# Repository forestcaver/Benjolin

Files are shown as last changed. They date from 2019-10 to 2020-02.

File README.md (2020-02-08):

# Benjolin

CC-By-NC 4.0, 2019

SMT Benjolin. Strictly for non-commercial use.

- - - -

This is a SMT version of the Benjolin with some modifications to power supply and protection.

Built and verified, Oct 2019

Rob Hordijk (the designer of the Benjolin) has kindly given permission Oct 27, 2019) for this to be shared on GitHub with the proviso that these files cannot be used by third parties for commercial use.

If you make changes and want to republish, please contact Rob before doing so!

- - - -

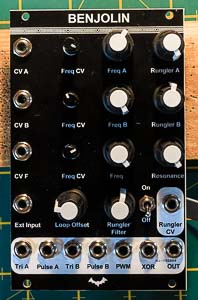
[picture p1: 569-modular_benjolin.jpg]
Benjolin


- - - -

## v1.0 ##

Files: Eagle pcb board, Eagle pcb schematic, Gerber files for the pcb, Eagle panel board, Gerber files for the panel (I use one-sided aluminium pcb with no copper), 2x images of the finished module

I used a combination of Kweiwen's schematic on his github as well as the electro-music schematics. I then added the power supply and protection.

The main issue (which is an original feature) for me is that the output volume is quite low. This is true of the original design. You can adjust one of the resistors just before the filter to boost the gain. But this can cause subtle distortion in the filter. A better way is to add a gain cell at the output (see v1.6)

- - - -

## v1.6 ##

This version adds an opamp to add gain to the output to approx 10v p-p. It also normalises T1 to osc 2 cv input
(can still be attenuated with the pot), normalises T2 to osc 1 cv and T2 to filter cv input.

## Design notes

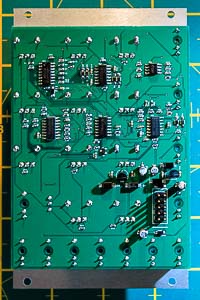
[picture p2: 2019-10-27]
568-modular_benjolin.jpg

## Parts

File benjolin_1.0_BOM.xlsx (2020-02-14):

benjolin_1.0_BOM
Qty | Value | Device | Package | Parts | Description | PROD_ID | VALUE
1 | 1.5k | R-US_R0603 | R0603 | R40 | RESISTOR, American symbol
6 | 100k | R-US_R0603 | R0603 | R11, R12, R17, R31, R44, R45 | RESISTOR, American symbol
17 | 100n | C-EUC0603 | C0603 | C5, C11, C12, C13, C14, C17, C18, C19, C20, C21, C22, C23, C24, C25, C26, C27, C28 | CAPACITOR, European symbol
3 | 10k | POT_USVERTICAL_NARROW | ALPS_POT_NARROW | R51, R52, R53
8 | 10k | POT_USVERTICAL_PS | ALPS_POT_VERTICAL_PS | R54, R55, R56, R57, R58, R59, R60, R61
5 | 10k | R-US_R0603 | R0603 | R7, R8, R29, R38, R46 | RESISTOR, American symbol
2 | 10u | CPOL-USA | PANASONIC_A | C15, C16 | POLARIZED CAPACITOR, American symbol
1 | 150k | R-US_R0603 | R0603 | R36 | RESISTOR, American symbol
5 | 15k | R-US_R0603 | R0603 | R13, R14, R22, R26, R39 | RESISTOR, American symbol
6 | 1N4148W-7 | 1N4148W-7 | SOD123 | D1, D2, D3, D4, D5, D6 | DIODE
3 | 1N5819HW | DIODE-SOD123 | SOD123 | D11, D100, D200 | DIODE
2 | 1n | C-EUC0603 | C0603 | C3, C4 | CAPACITOR, European symbol
4 | 1n4004 | D-SMA | DO-214AC | D7, D8, D9, D10 | DIODE
3 | 220p | C-EUC0603 | C0603 | C7, C8, C10 | CAPACITOR, European symbol
1 | 2n3904 | TRANS_NPN-MMBT2222AL | SOT23-3 | Q1 | NPN transistor | TRANS-08049 | 600mA/40V
16 | 30k | R-US_R0603 | R0603 | R3, R5, R15, R16, R19, R20, R23, R24, R25, R27, R28, R32, R33, R34, R47, R48 | RESISTOR, American symbol
2 | 4.7u | CPOL-USA | PANASONIC_A | C100, C200 | POLARIZED CAPACITOR, American symbol
1 | 4021D | 4021D | SO16 | IC1 | 8-bit static SHIFT REGISTER
1 | 470k | R-US_R0603 | R0603 | R50 | RESISTOR, American symbol
1 | 47k (was 62k) | R-US_R0603 | R0603 | R18 | RESISTOR, American symbol
4 | 510 | R-US_R0603 | R0603 | R9, R10, R37, R49 | RESISTOR, American symbol
9 | 51k | R-US_R0603 | R0603 | R1, R2, R4, R6, R30, R35, R41, R42, R43 | RESISTOR, American symbol
4 | 560p | C-EUC0603 | C0603 | C1, C2, C6, C9 | CAPACITOR, European symbol
1 | 62k | R-US_R0603 | R0603 | R21 | RESISTOR, American symbol
1 | M05X2PTH | M05X2PTH | AVR_ICSP | JP1 | Header 5x2
12 | PJ301_THONKICONN6 | PJ301_THONKICONN6 | WQP_PJ_301M6 | J1, J2, J3, J4, J5, J6, J7, J8, J9, J10, J11, J12
1 | SSM2164S | SSM2164S | SOIC16N | IC3
1 | TL072D | TL072D | SO08 | IC4 | OP AMP
3 | TL074D | TL074D | SO14 | IC2, IC5, IC6 | OP AMP
1 | lm78l09 | 78LXX | 78LXX | IC7 | VOLTAGE REGULATOR
1 | lm79l09 | 79LXX | 79LXX | IC8 | VOLTAGE REGULATOR
1 | submini-2T | SPDTT | SPDT-SUB | SW1 | SPDT Switch

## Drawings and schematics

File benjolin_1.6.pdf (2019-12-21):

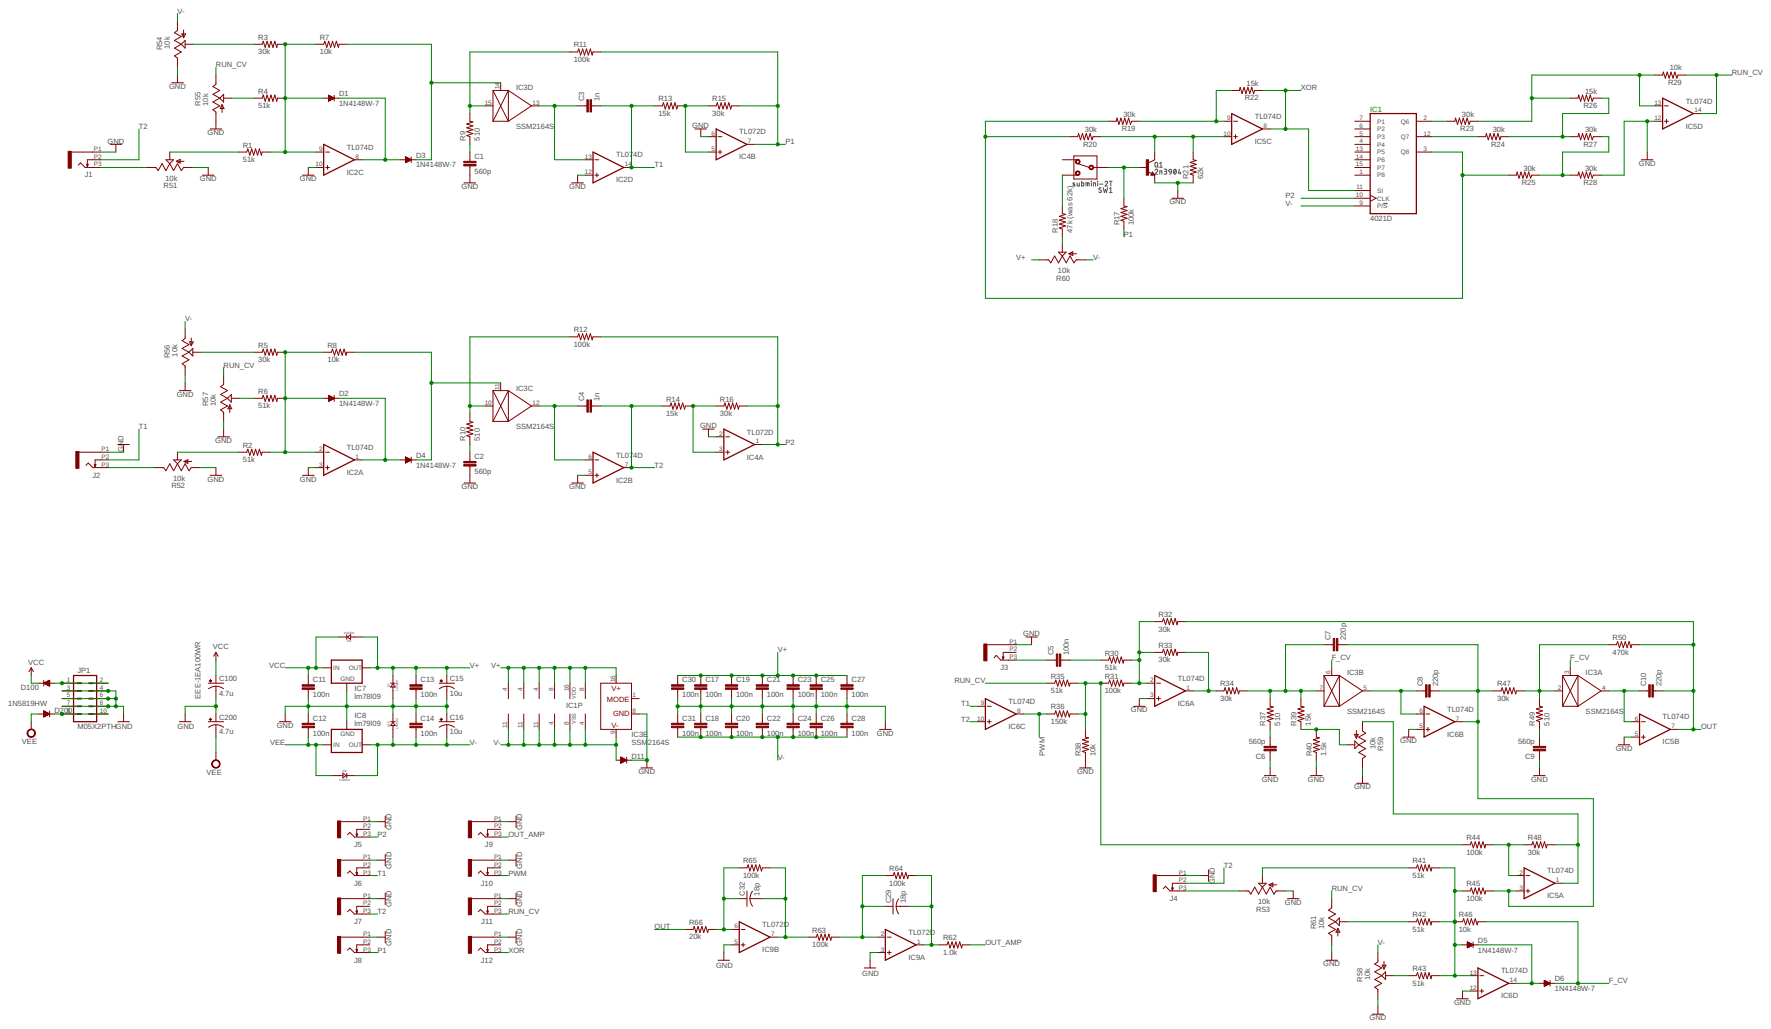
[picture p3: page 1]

GND GND

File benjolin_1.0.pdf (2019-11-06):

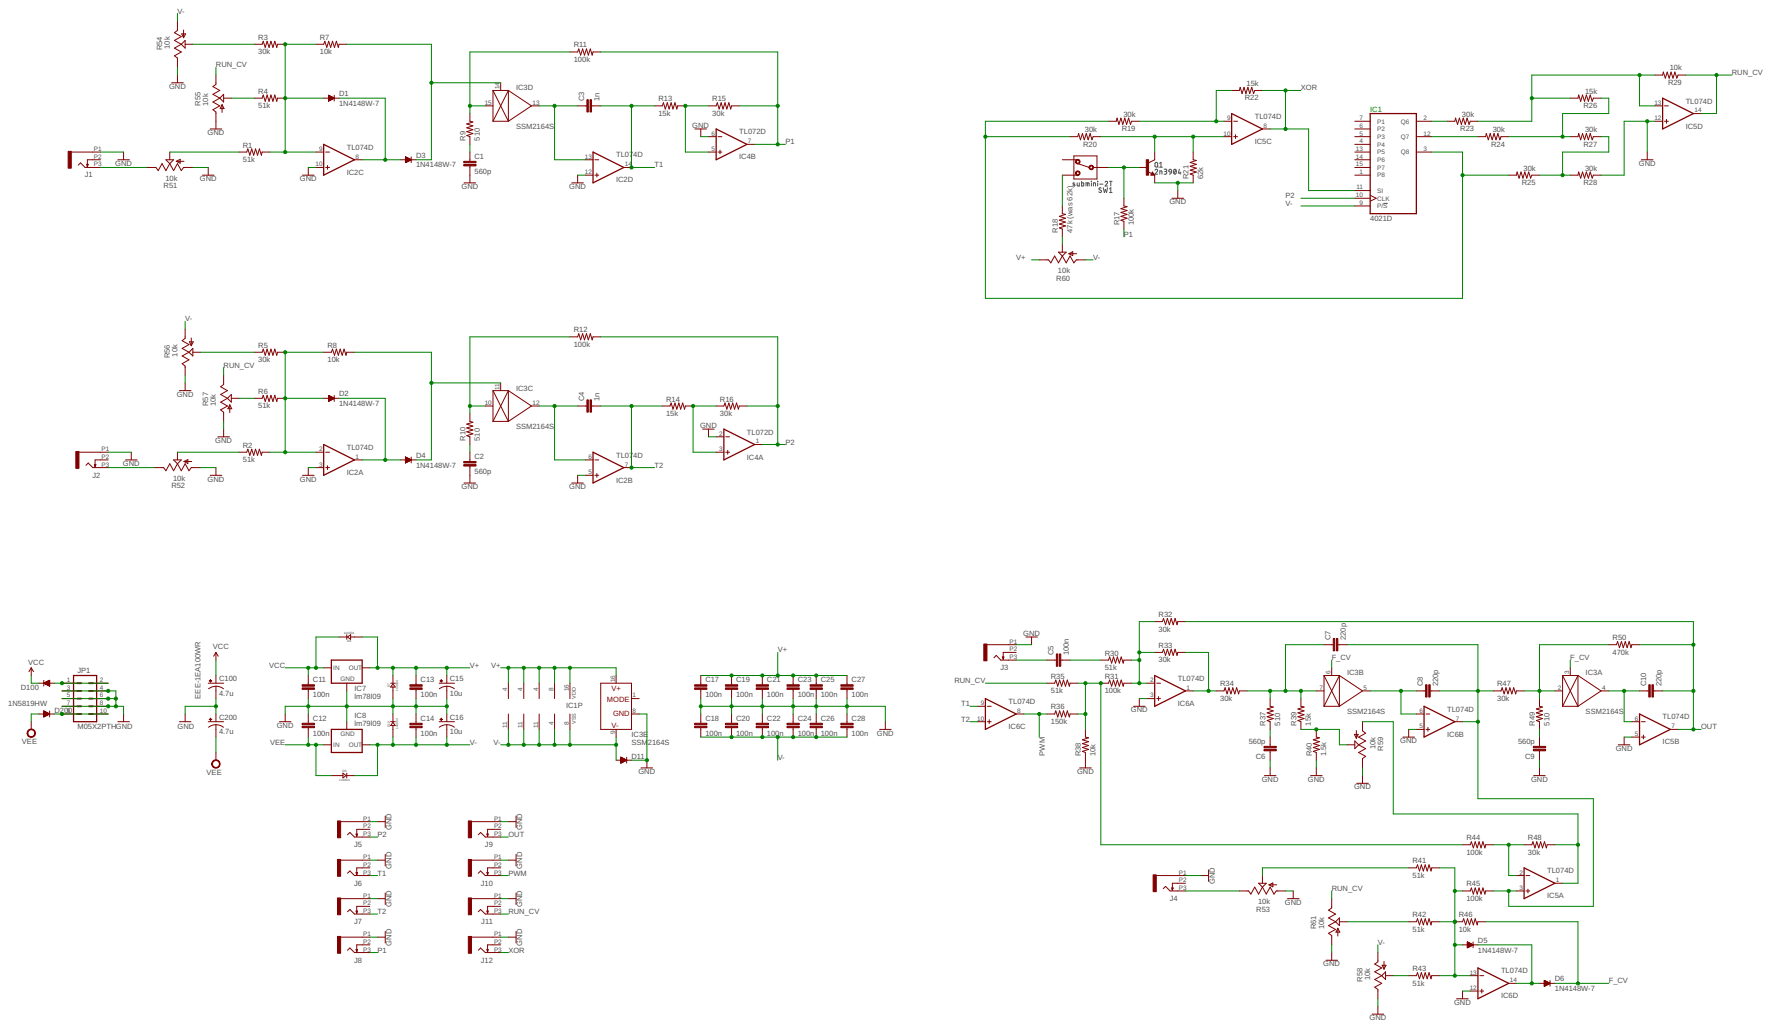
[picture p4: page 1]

GND GND

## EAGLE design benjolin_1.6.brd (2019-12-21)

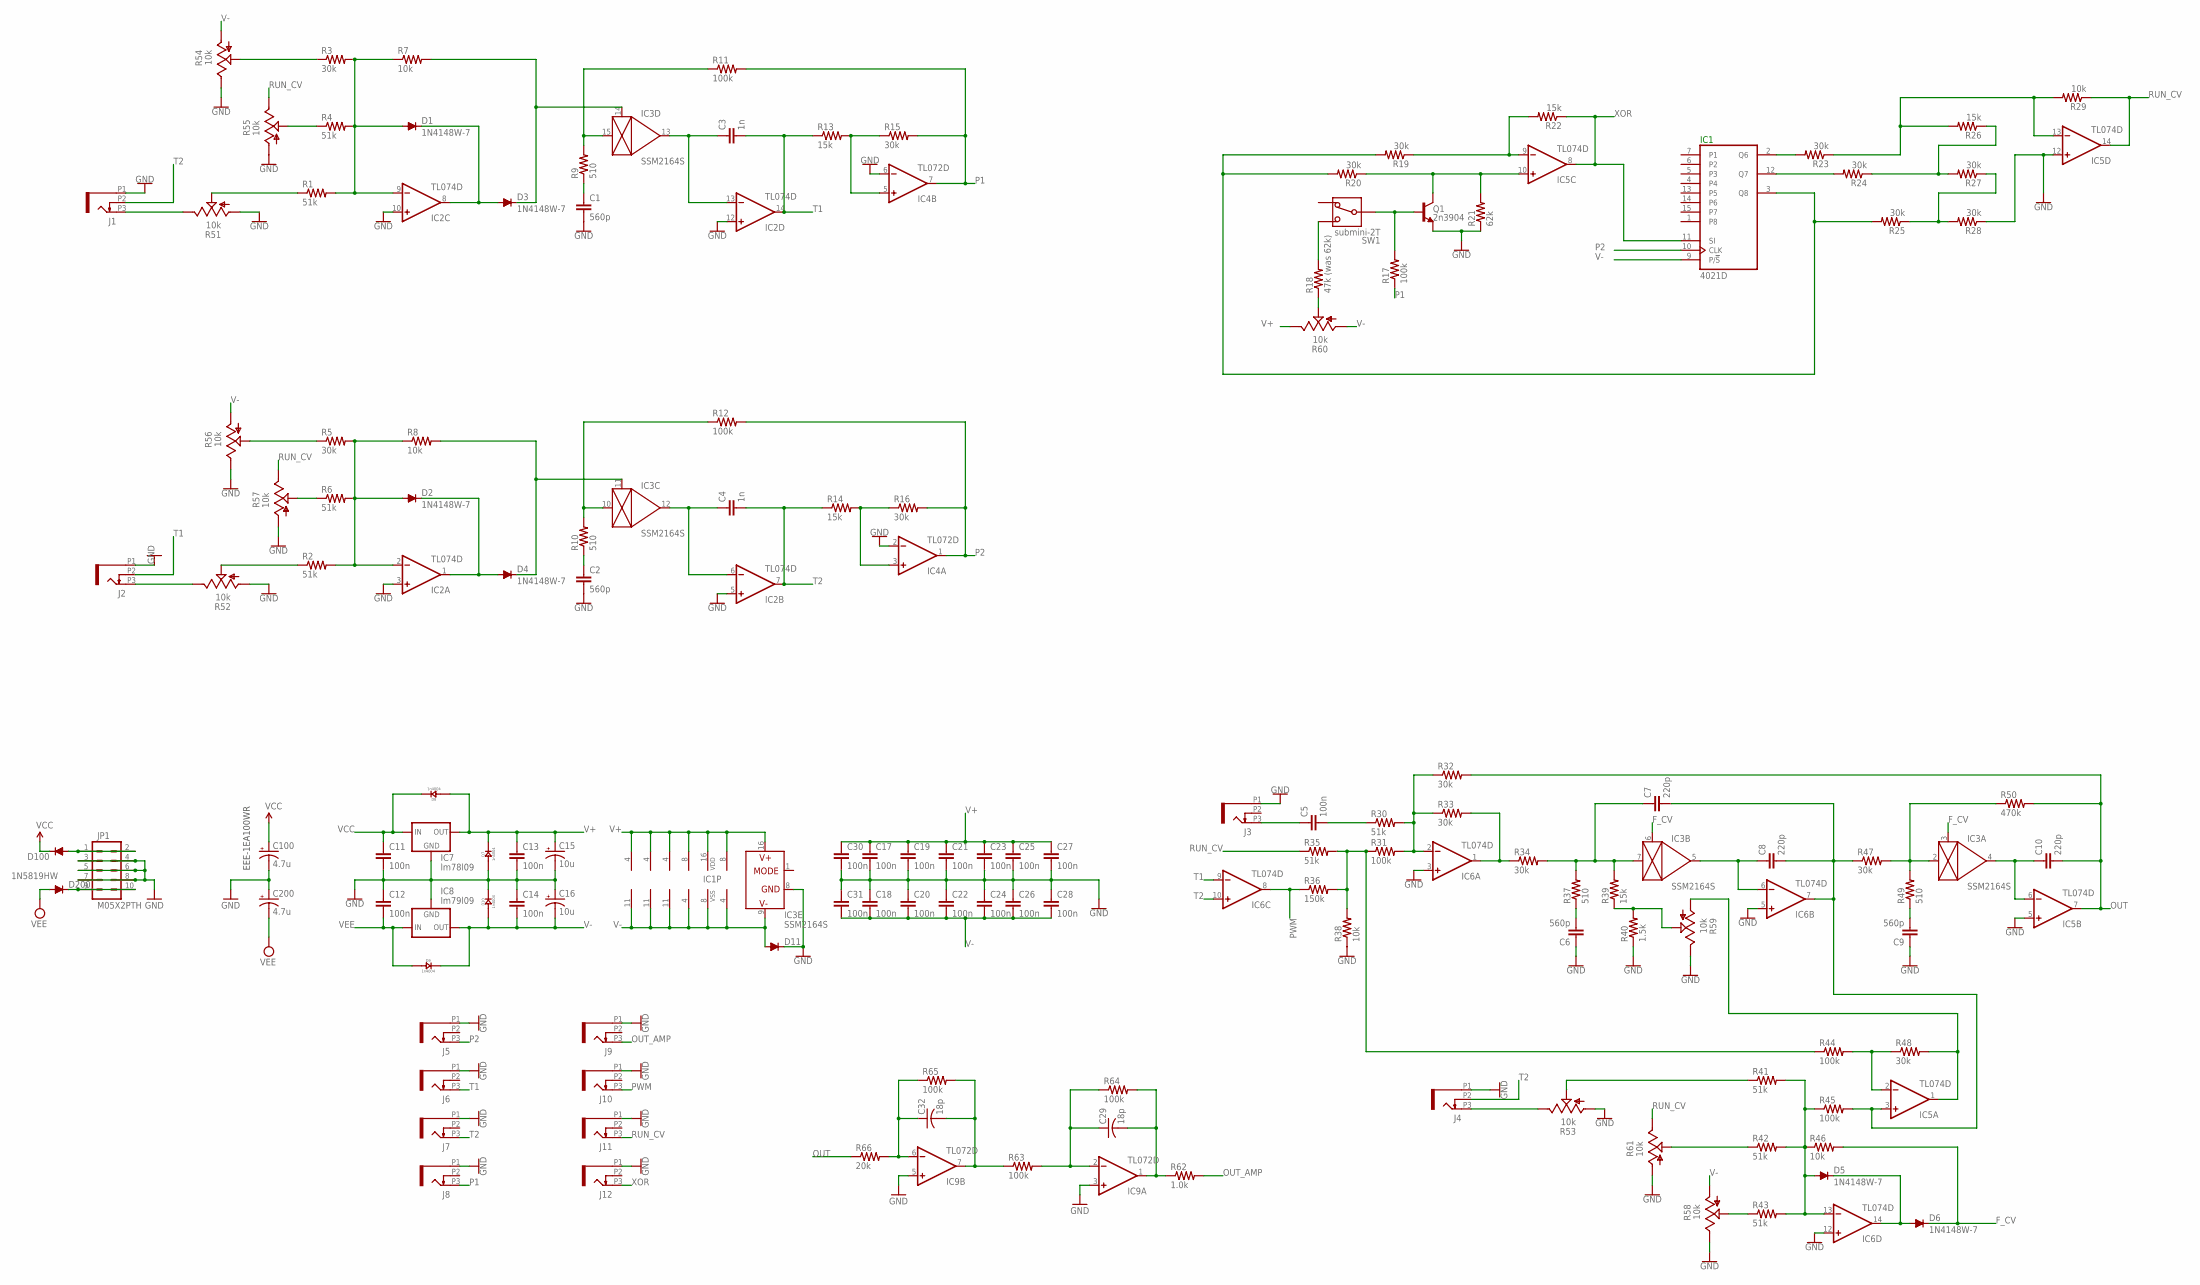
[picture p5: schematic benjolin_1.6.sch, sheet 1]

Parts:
C1, C2, C6, C9: 560p; C0603
C3, C4: 1n; C0603
C5, C11, C12, C13, C14, C17, C18, C19, C20, C21, C22, C23, C24, C25, C26, C27, C28, C30, C31: 100n; C0603
C7, C8, C10: 220p; C0603
C15, C16: 10u; PANASONIC_A
C29, C32: 18p; C0603
C100, C200: 4.7u; PANASONIC_A
D1, D2, D3, D4, D5, D6: 1N4148W-7; SOD123
D7, D8, D9, D10: 1n4004; DO-214AC
D11, D100, D200: 1N5819HW; SOD123
IC1: 4021D; SO16
IC2, IC5, IC6: TL074D; SO14
IC3: SSM2164S; SOIC16N
IC4, IC9: TL072D; SO08
IC7: lm78l09; 78LXX
IC8: lm79l09; 79LXX
J1, J2, J3, J4, J5, J6, J7, J8, J9, J10, J11, J12: PJ301_THONKICONN6; WQP_PJ_301M6
JP1: M05X2PTH; AVR_ICSP
Q1: 2n3904; SOT23-3
R1, R2, R4, R6, R30, R35, R41, R42, R43: 51k; R0603
R3, R5, R15, R16, R19, R20, R23, R24, R25, R27, R28, R32, R33, R34, R47, R48: 30k; R0603
R7, R8, R29, R38, R46: 10k; R0603
R9, R10, R37, R49: 510; R0603
R11, R12, R17, R31, R44, R45, R63, R64, R65: 100k; R0603
R13, R14, R22, R26, R39: 15k; R0603
R18: 47k (was 62k); R0603
R21: 62k; R0603
R36: 150k; R0603
R40: 1.5k; R0603
R50: 470k; R0603
R51, R52, R53: 10k; ALPS_POT_NARROW
R54, R55, R56, R57, R58, R59, R60, R61: 10k; ALPS_POT_VERTICAL_PS
R62: 1.0k; R0603
R66: 20k; R0603
SW1: submini-2T; SPDT-SUB

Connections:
F_CV: D6.C, IC3.3 (CTRL), IC3.6 (CTRL), R46.2
GND: C1.2, C2.2, C6.1, C9.1, C11.2, C12.1, C13.2, C14.1, C15.-, C16.+, C17.2, C18.1, C19.2, C20.1, C21.2, C22.1, C23.2, C24.1, C25.2, C26.1, C27.2, C28.1, C30.2, C31.1, C100.-, C200.+, D7.1 (+), D10.2 (-), D11.C, IC2.3 (+IN), IC2.5 (+IN), IC2.10 (+IN), IC2.12 (+IN), IC3.8 (GND), IC4.2 (-IN), IC4.6 (-IN), IC5.5 (+IN), IC5.12 (+IN), IC6.3 (+IN), IC6.5 (+IN), IC6.12 (+IN), IC7.GND, IC8.GND, IC9.3 (+IN), IC9.5 (+IN), J1.P1 (1), J2.P1 (1), J3.P1 (1), J4.P1 (1), J5.P1 (1), J6.P1 (1), J7.P1 (1), J8.P1 (1), J9.P1 (1), J10.P1 (1), J11.P1 (1), J12.P1 (1), JP1.3, JP1.4, JP1.5, JP1.6, JP1.7, JP1.8, Q1.2 (E), R21.1, R28.1, R38.1, R40.1, R51.P$3 (A), R52.P$3 (A), R53.P$3 (A), R54.P$1 (E), R55.P$3 (A), R56.P$1 (E), R57.P$3 (A), R58.P$1 (E), R59.P$1 (E), R61.P$3 (A)
unnamed: J1.P3 (3), R51.P$1 (E)
unnamed: J2.P3 (3), R52.P$1 (E)
unnamed: R1.1, R51.P$2 (S)
unnamed: R2.1, R52.P$2 (S)
unnamed: D1.A, IC2.9 (-IN), R1.2, R3.2, R4.2, R7.1
unnamed: D100.A, JP1.1, JP1.2
unnamed: D2.A, IC2.2 (-IN), R2.2, R5.2, R6.2, R8.1
unnamed: R6.1, R57.P$2 (S)
unnamed: R5.1, R56.P$2 (S)
unnamed: R3.1, R54.P$2 (S)
unnamed: R4.1, R55.P$2 (S)
unnamed: D1.C, D3.A, IC2.8 (OUT)
unnamed: D4.C, IC3.11 (CTRL), R8.2
unnamed: D2.C, D4.A, IC2.1 (OUT)
unnamed: D3.C, IC3.14 (CTRL), R7.2
unnamed: R43.1, R58.P$2 (S)
unnamed: C29.2, IC9.1 (OUT), R62.1, R64.2
unnamed: C2.1, R10.1
unnamed: IC3.10 (IN), R10.2, R12.1
unnamed: D200.C, JP1.9, JP1.10
unnamed: IC3.15 (IN), R9.2, R11.1
unnamed: C1.1, R9.1
unnamed: C4.1, IC2.6 (-IN), IC3.12 (OUT)
unnamed: C3.1, IC2.13 (-IN), IC3.13 (OUT)
unnamed: IC4.3 (+IN), R14.2, R16.1
unnamed: IC4.5 (+IN), R13.2, R15.1
unnamed: R18.2, SW1.P$1
unnamed: R18.1, R60.P$2 (S)
unnamed: Q1.1 (B), R17.2, SW1.P$2
unnamed: IC5.10 (+IN), Q1.3 (C), R20.1, R21.2
unnamed: IC5.9 (-IN), R19.1, R22.2
unnamed: IC1.2 (Q6), R23.2
unnamed: IC1.12 (Q7), R24.2
unnamed: IC1.3 (Q8), R19.2, R20.2, R25.2
unnamed: R24.1, R26.1, R27.2
unnamed: R25.1, R27.1, R28.2
unnamed: IC5.13 (-IN), R23.1, R26.2, R29.2
unnamed: R31.1, R35.2, R36.2, R38.2, R44.1
unnamed: C5.1, J3.P3 (3)
unnamed: C5.2, R30.1
unnamed: IC6.2 (-IN), R30.2, R31.2, R32.1, R33.1
unnamed: IC6.1 (OUT), R33.2, R34.1
unnamed: IC5.2 (-IN), R44.2, R48.1
unnamed: R39.1, R40.2, R59.P$2 (S)
unnamed: C6.2, R37.1
unnamed: C7.1, IC3.7 (IN), R34.2, R37.2, R39.2
unnamed: C8.1, IC3.5 (OUT), IC6.6 (-IN)
unnamed: C7.2, C8.2, IC5.3 (+IN), IC6.7 (OUT), R45.2, R47.1
unnamed: D5.A, IC6.13 (-IN), R41.2, R42.2, R43.2, R45.1, R46.1
unnamed: C9.2, R49.1
unnamed: IC3.2 (IN), R47.2, R49.2, R50.1
unnamed: C10.1, IC3.4 (OUT), IC5.6 (-IN)
unnamed: IC5.1 (OUT), R48.2, R59.P$3 (A)
unnamed: D5.C, D6.A, IC6.14 (OUT)
unnamed: R42.1, R61.P$2 (S)
unnamed: J4.P3 (3), R53.P$1 (E)
unnamed: R41.1, R53.P$2 (S)
unnamed: C32.1, IC9.6 (-IN), R65.1, R66.2
unnamed: C29.1, IC9.2 (-IN), R63.2, R64.1
unnamed: C32.2, IC9.7 (OUT), R63.1, R65.2
OUT: C10.2, IC5.7 (OUT), R32.2, R50.2, R66.1
OUT_AMP: J9.P3 (3), R62.2
P1: IC4.7 (OUT), J8.P3 (3), R11.2, R15.2, R17.1
P2: IC1.10 (CLK), IC4.1 (OUT), J5.P3 (3), R12.2, R16.2
PWM: IC6.8 (OUT), J10.P3 (3), R36.1
RUN_CV: IC5.14 (OUT), J11.P3 (3), R29.1, R35.1, R55.P$1 (E), R57.P$1 (E), R61.P$1 (E)
T1: C3.2, IC2.14 (OUT), IC6.9 (-IN), J2.P2 (2), J6.P3 (3), R13.1
T2: C4.2, IC2.7 (OUT), IC6.10 (+IN), J1.P2 (2), J4.P2 (2), J7.P3 (3), R14.1
V+: C13.1, C15.+, C17.1, C19.1, C21.1, C23.1, C25.1, C27.1, C30.1, D7.2 (-), D8.1 (+), IC1.16 (VDD), IC2.4 (V+), IC3.16 (V+), IC4.8 (V+), IC5.4 (V+), IC6.4 (V+), IC7.OUT, IC9.8 (V+), R60.P$1 (E)
V-: C14.2, C16.-, C18.2, C20.2, C22.2, C24.2, C26.2, C28.2, C31.2, D9.2 (-), D10.1 (+), D11.A, IC1.8 (VSS), IC1.9 (P/!S), IC2.11 (V-), IC3.9 (V-), IC4.4 (V-), IC5.11 (V-), IC6.11 (V-), IC8.OUT, IC9.4 (V-), R54.P$3 (A), R56.P$3 (A), R58.P$3 (A), R60.P$3 (A)
VCC: C11.1, C100.+, D8.2 (-), D100.C, IC7.IN
VEE: C12.2, C200.-, D9.1 (+), D200.A, IC8.IN
XOR: IC1.11 (SI), IC5.8 (OUT), J12.P3 (3), R22.1

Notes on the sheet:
EEE-1EA100WR

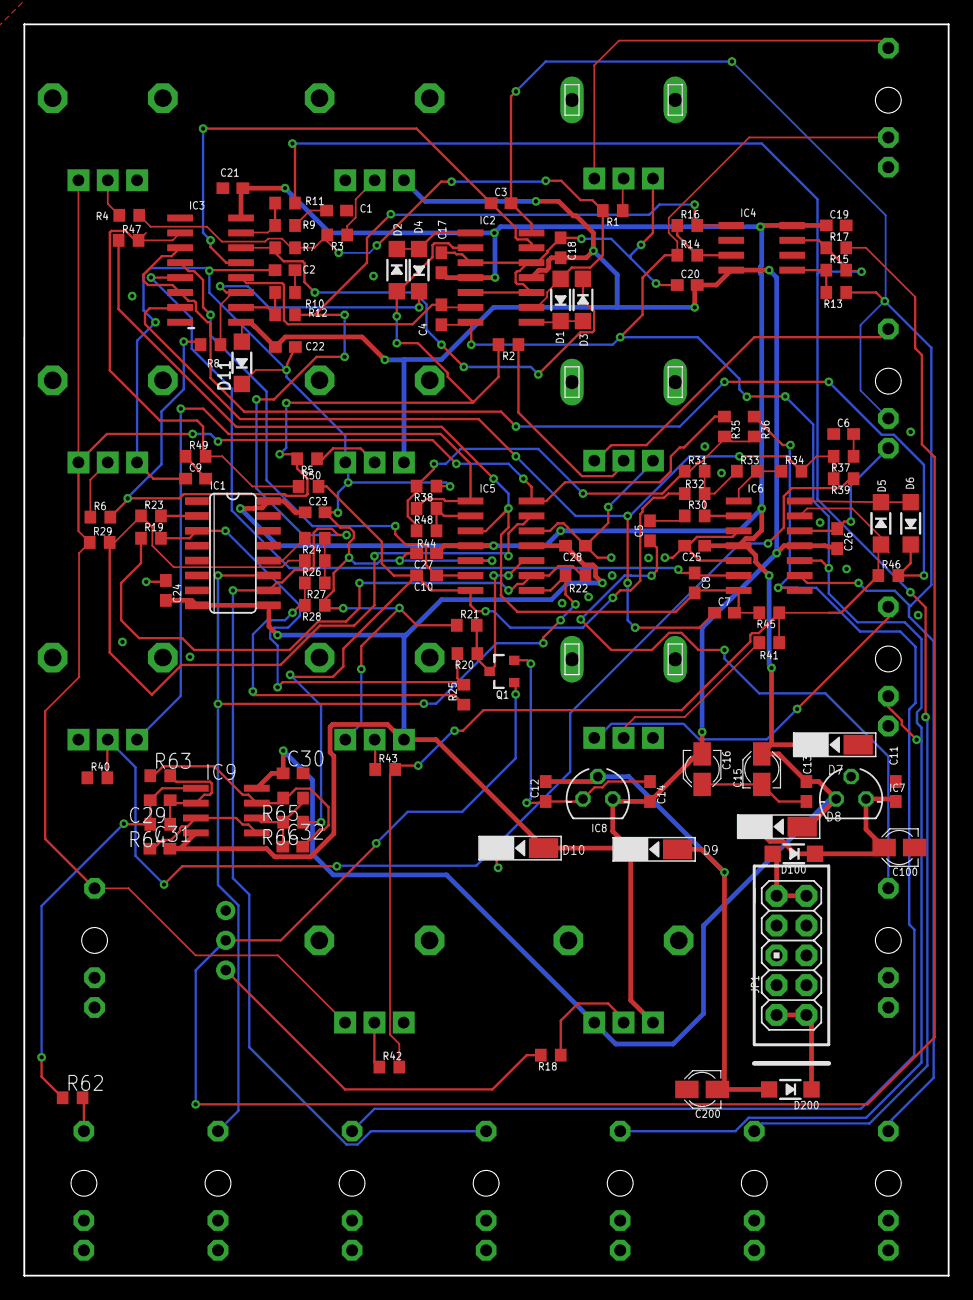
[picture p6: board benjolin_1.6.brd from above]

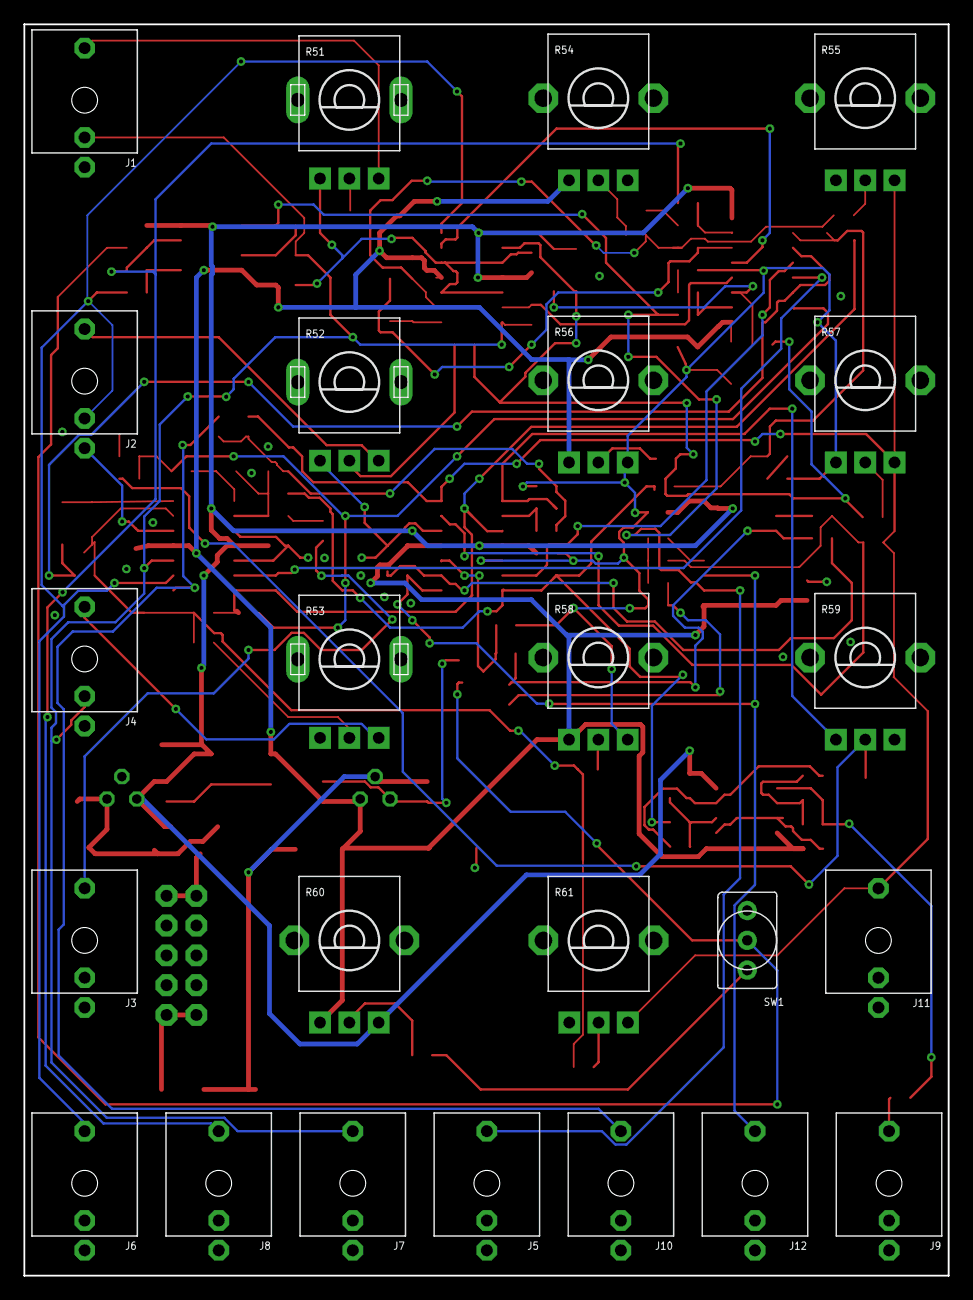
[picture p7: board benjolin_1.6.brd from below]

Board: 2 copper layers, 78.8 x 106.7 mm, 137 parts (24 on the bottom side), 75 nets.

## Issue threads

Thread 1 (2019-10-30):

normalling VCO1 to VCO2 cv and vice versa

av500, 2019-10-30:
hi there,

why not hook it up like a standalone Benjolin and normal VCO1 TRI to VCO2 CV in and VCO2 TRI to VCO1 CV in? it make it much more useful without the need for patching.

forestcaver, 2019-10-30:
Thanks Vlad - I didnt know the standalone one did that ! It took me a fair bit of searching to find schematics that showed it.... All the schematics I’d found on electro-music and for modular benjolins (euro, 4u and 5u) didnt have that normalling so it didnt cross my mind..... and I didnt think
about it !

I guess with the attenuation you don’t lose anything at all by doing that normalling..... it’s a good idea - I’ll add it to the next revision. I’ll also increase the gain after the filter when I revise it.

I’ll try to add it and test the board before christmas.

Thanks.

forestcaver, 2019-11-05:
Added the above, along with normalling to filter cv input (still needs testing)

av500, 2019-11-06:
btw, would be nice to have the schematics as a PDF in git as well, not everybody has Eagle on their phone :)

forestcaver, 2019-11-06:
Schematic uploaded :-)

forestcaver, 2019-12-21:
Fixed in v1.6

Closed 2019-12-21.

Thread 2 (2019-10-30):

Increase gain of output

forestcaver, 2019-10-30:
The stock benjolin has a low (~1.5v p-p output). I’ll add a gain cell on the next revision

forestcaver, 2019-11-05:
Done on a test board - needs testing and uploading

forestcaver, 2019-12-21:
Fixed in v1.6

Closed 2019-12-21.

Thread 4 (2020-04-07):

IC Orientation

Microfi, 2020-04-07:
Thank you for this wonderful project, forestcaver!

I just received my PCB's and I was wondering what the orientation of the IC's is.
For IC1 this is indicated on the silkscreen, but I don't see this same indication for the other IC's.

forestcaver, 2020-04-07:
Have a look in eagle (download the free version). All the design files are there. Orientation is seen in tdocu and tplace layers. You can generate gerbers with those layers in the silkscreen if you wanted.

Microfi, 2020-04-07:
> Have a look in eagle (download the free version). All the design files are there. Orientation is seen in tdocu and tplace layers. You can generate gerbers with those layers in the silkscreen if you wanted.

Those layers indeed contained the information. Thanks a lot for your help!

forestcaver, 2020-04-07:
No problem - enjoy.

Closed 2020-04-07.

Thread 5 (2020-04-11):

sourcing parts from bom

langolierz, 2020-04-11:
hi @forestcaver thanks a lot for sharing this !

i am currently sourcing parts for this build and there are a few things that confused me (this is my first time looking for smd parts though so might just be me) , thought i would share them here anyway. maybe they will help someone. i am looking for parts on mouser.

- it wasnt that obvious what the `PANASONIC_A` footprint meant ... i ended up grabbing some that had 4mm diameter
- i couldnt really figure out the difference between the `POT_USVERTICAL_PS` and `POT_USVERTICAL_NARROW`. (can see on the pcb that the holes are smaller on narrow, but couldnt find a part that explicitly says 'narrow') is there a reason why you didnt just use a footprint that would fit both ? (oh and maybe it should say that the pots are linear ? )
-  i couldnt find a 1n4004 in D-SMA , went for this BYG21M-E3 instead
- (probably this is well known but) SSM2164S is discontinued. you can get the replacement V2164M from places like thonk (although not from mouser )
- mouser doesnt stock lm79l09 or any -9v linear regulators. i will have to get this from ebay or something i guess..
- seems will have to source sub-mini switches from thonk also, cant find them on mouser (or tayda)

forestcaver, 2020-04-12:
Sorry to hear about your part sourcing problems

panasonic A, B,C and D are standard footprint sizes for electrolytics.

The two pot footprints are for tall trimmers and alpha/alps pots
The part value is in the eagle files,

I just checked this morning and mouser has several hundred thousand of those diodes so they’re not uncommon. Just check the response time of your chosen substitute - 1n409x are chosen for a reason...

2164 - I use v2164 as I have loads but ssi and alfa also make them. You can probably omit the protection diode if you use ssi (and maybe alfa - havent checked) but not if you use coolaudio.

Mouser doesnt stock everything all the time. There are other places to get parts eg voltage regulators.

Mouser does sell sub mini toggle switches, however. (But they’re cheaper elsewhere)

Sometimes, with diy projects, you wont find everything at mouser and will sometimes need to source parts yourself from other suppliers.

Closed 2020-04-12.

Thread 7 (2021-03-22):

4021D IC references

Klodifokan, 2021-03-22:
Hi,

I'd like to build a Benjolin but I can't find a 4021D IC.
Do you have a reference from Mouser or another website please?

Thanks for your help.

forestcaver, 2021-03-22:
There are thousands on Mouser - just checked. I’m closing this as it’s not an issue with the module.
I’m sorry - I can’t offer any further build or parts sourcing support.

Klodifokan, 2021-03-22:
Thanks
this is what I call help

forestcaver, 2021-03-22:
This one will work....

https://www.mouser.co.uk/ProductDetail/595-CD4021BM96

Klodifokan, 2021-03-22:
Et bien voilà
Thanks

Closed 2021-03-22.

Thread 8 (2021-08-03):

Pot footprint and panel hole

jamesbondsai, 2021-08-03:
Small note while building. I use alpha pots and Song Huei tall trimmers. I noticed that the holes for the ground legs on the song huei footprint are way too small to fit any ground legs. (I just cut them off in my case).
I also noticed that the panel hole for R60 (alpha pot) has a diameter of 6.5mm (tall trimmer size) instead of 7.5 on the other alpha pot holes. Will drill it out, no problem. But I thought I'd let you know :).

Thanks a lot for your work, on the benjolin and other modules!

forestcaver, 2021-08-06:
Thanks - I didnt have any issues with the tall trimmers and I dont believe others have.... sometimes the board manufacturer you choose doesnt implement the milling correctly (have a look at the board file - there are milling slots for the tall trimmers.... Have a look at the gerbers in a gerber viewer - there are plated slots clearly shown for the tall trimmers....

R60 - yeah - should be slightly larger !!! Thanks ! (But I’m not going to change it and reorder panels to test just yet :-) ) I have plans to update the benjolin and have made quite a few changes but not got around to ordering test pcbs yet as I’m occasionally making a few more changes.... I’ll update it when I get around to finalising some ideas....

Closed 2021-08-06.

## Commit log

2019-11-06 Add schematic pdf
2019-12-21 v1.6 - gain cell, normalisations
    [benjolin_1.6.brd, benjolin_1.6.sch]
2020-02-14 Added BOMs
    [benjolin_1.0_BOM.xlsx, benjolin_1.6_BOM.xlsx]

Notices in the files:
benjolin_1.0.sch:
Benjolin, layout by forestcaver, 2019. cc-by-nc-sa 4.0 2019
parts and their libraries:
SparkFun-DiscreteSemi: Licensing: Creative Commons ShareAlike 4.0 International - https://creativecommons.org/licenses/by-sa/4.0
